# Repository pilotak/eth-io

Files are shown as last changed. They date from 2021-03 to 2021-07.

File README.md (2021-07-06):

<p align="center">
  
</p>
<p align="center">
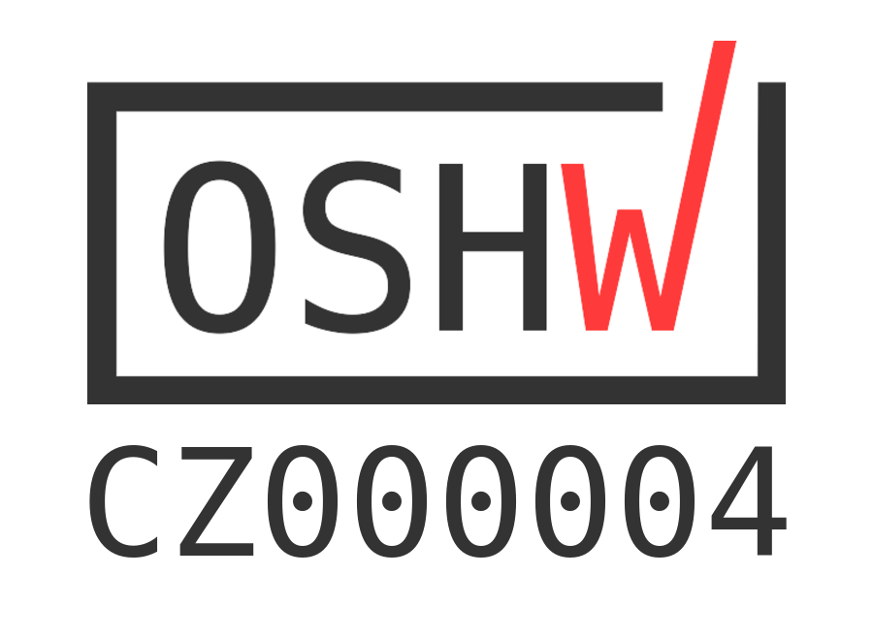
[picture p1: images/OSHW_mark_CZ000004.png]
  
</p>

# ETH IO
ESP32 based ethernet I/O board for home automation compatible with ESPHome, Tasmota, etc.

**Features**:
- wide range of input voltage 6-28V
- 4x opto-isolated "fast" operation inputs (connected to GPIO)
- 16x opto-isolated general inputs (connected to MCP23017 expander)
- 2x PWM capable low-side fully protected switches (connected to GPIO)
- 16x low-side fully protected switches for switching the non-latching relays or SSR relays (connected to MCP23017 expander)
- daisy chain design - see below

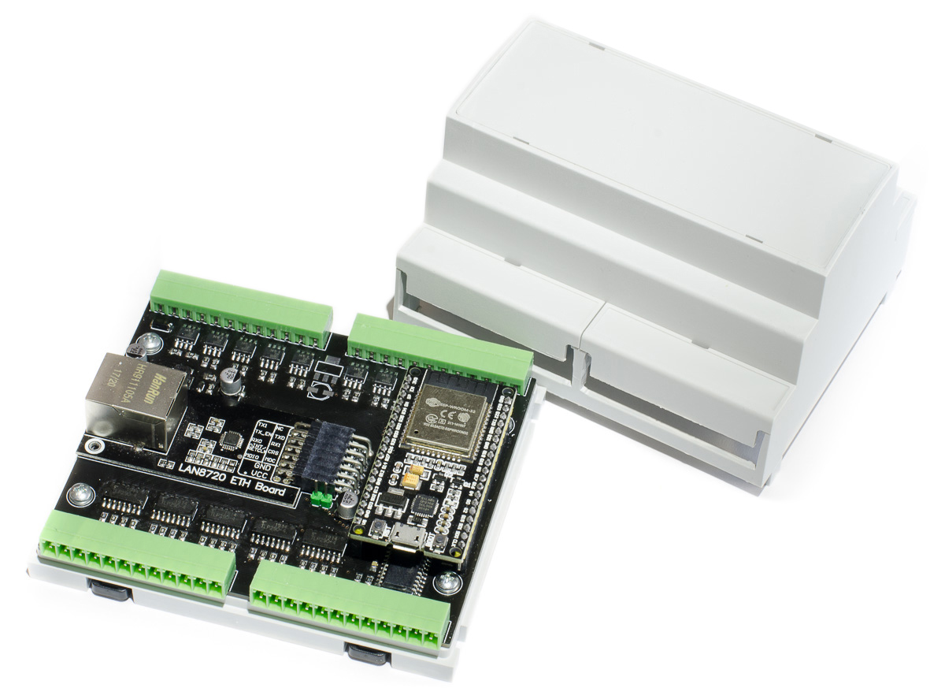
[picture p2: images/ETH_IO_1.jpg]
ETH_IO_1

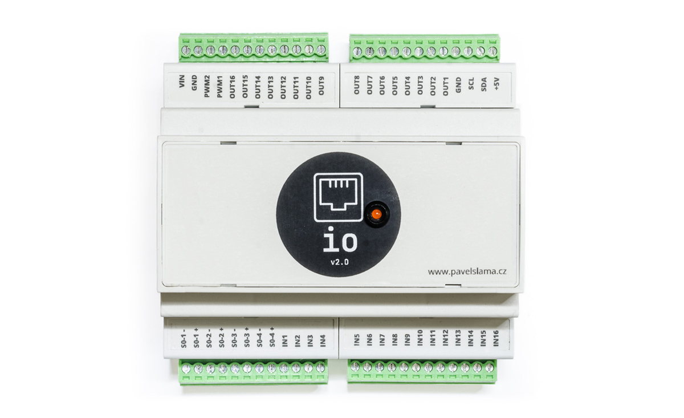
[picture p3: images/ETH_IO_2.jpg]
ETH_IO_2


## Basic wiring
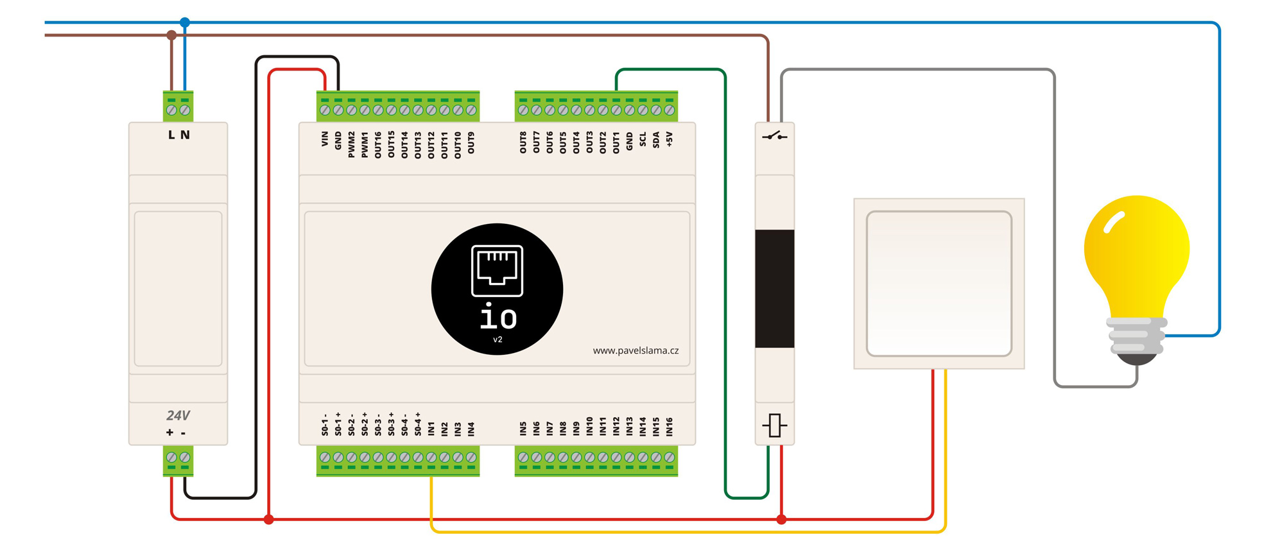
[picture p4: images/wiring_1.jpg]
Wiring 1


## "Fast" inputs
Are meant to be used for reading pulses from utility meter ie. power meter with S0 output
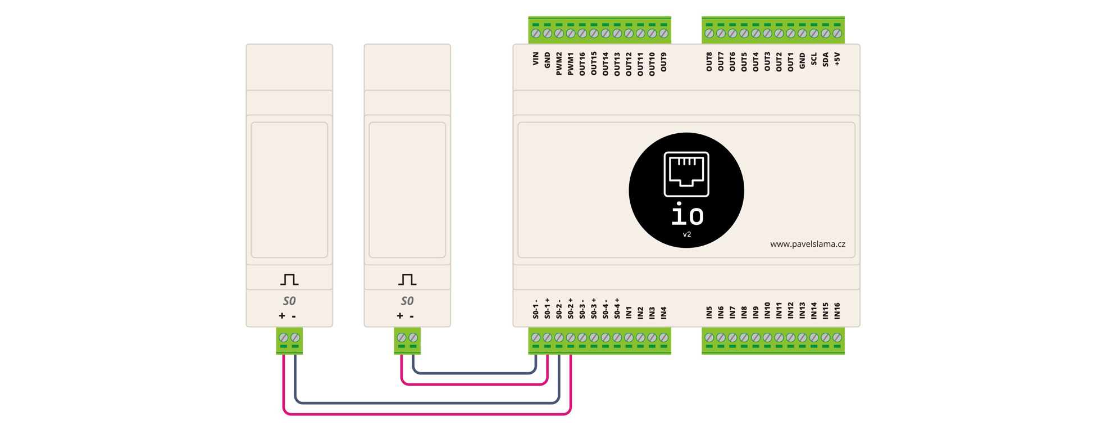
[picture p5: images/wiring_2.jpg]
Wiring 2


## Daisy chain design
Should you need more inputs/outputs (up to 96 more inputs/outputs or combination thanks to changing the address of MCP23017) you can use the same PCB. Just don't populate ETH breakout board and ESP32 and solder AMS1117-3.3 with its capacitor. The boards will be connected via SDA/SCL but thanks to a bus buffer (P82B96) communication can easilly be made up to 20 meters (possibly more by reducing speed of I2C bus)!
> In this mode the "slave" device can't make use of S0 inputs nor the PWM outputs

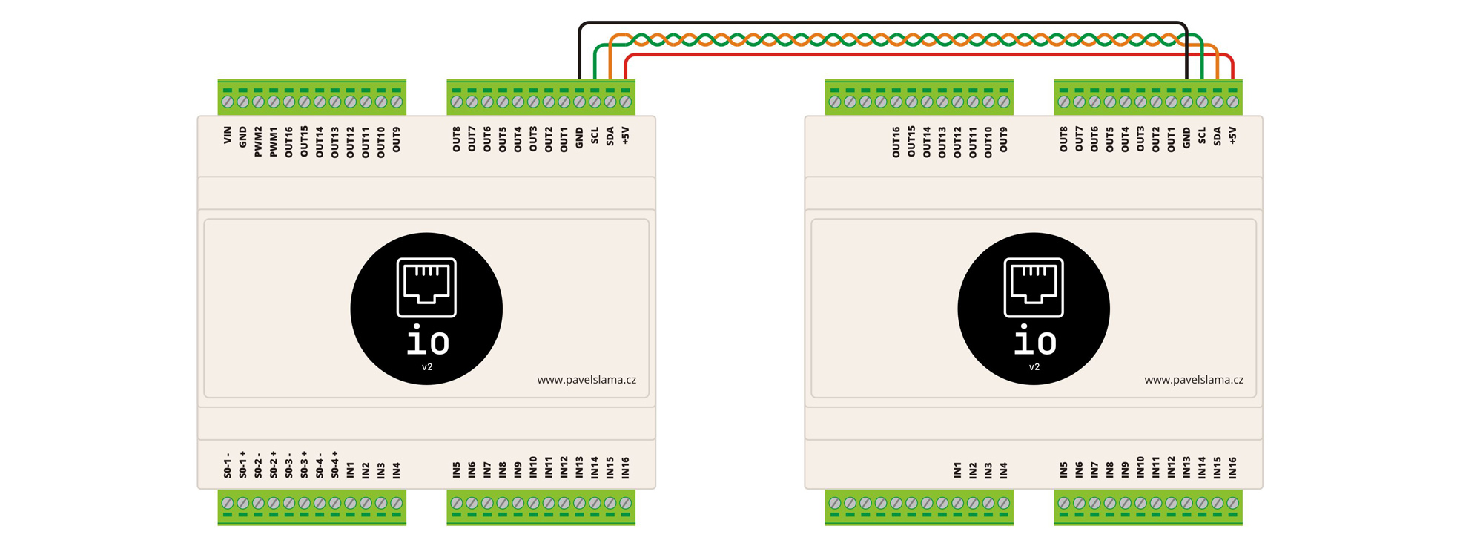
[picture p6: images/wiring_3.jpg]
Wiring 3


_For more information please visit [wiki](https://github.com/pilotak/eth-io/wiki)_

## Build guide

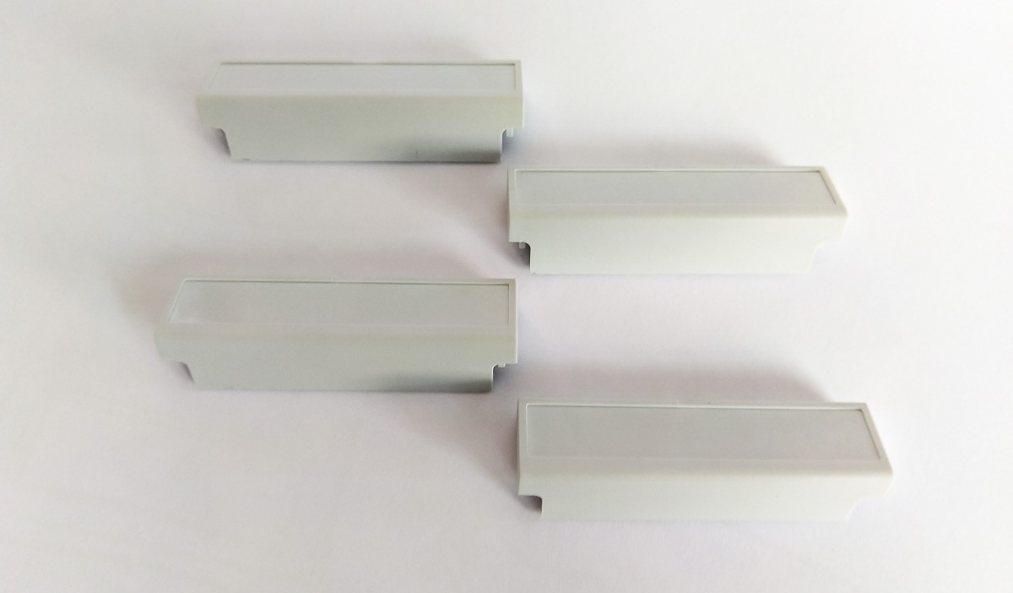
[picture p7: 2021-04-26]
images/assembly/7.jpg

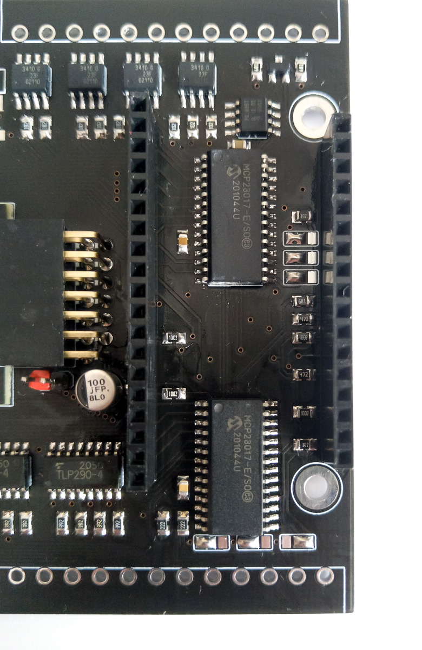
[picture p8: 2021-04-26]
images/assembly/3.jpg

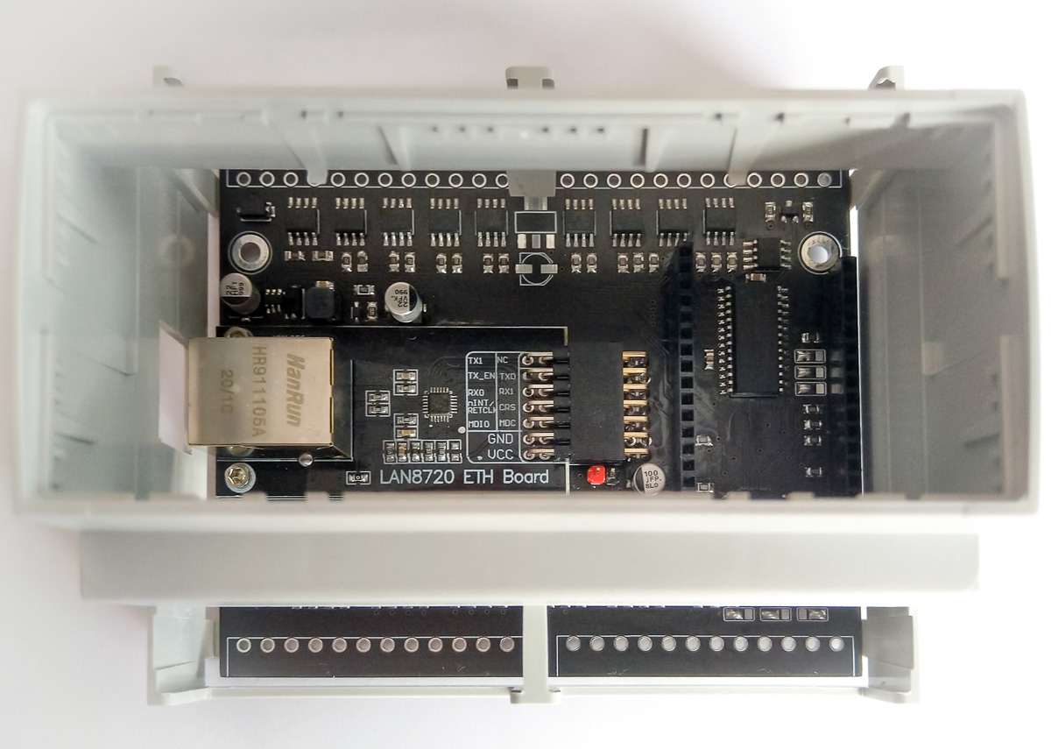
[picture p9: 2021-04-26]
images/assembly/2.jpg

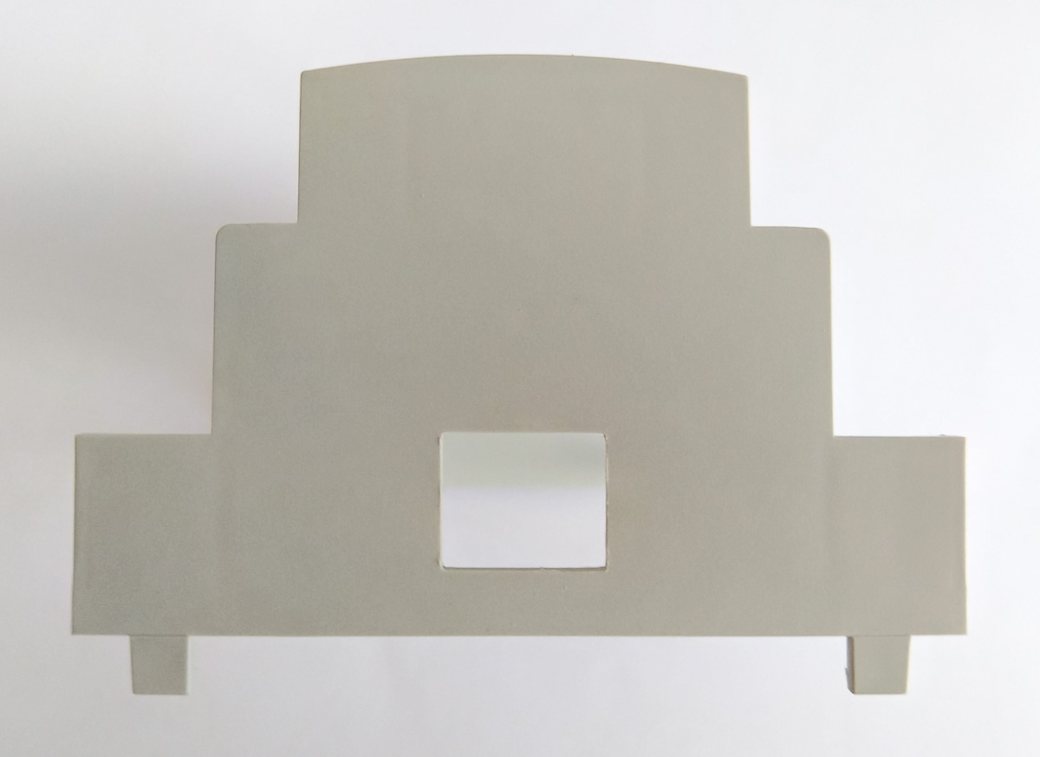
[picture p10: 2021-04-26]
images/assembly/5.jpg

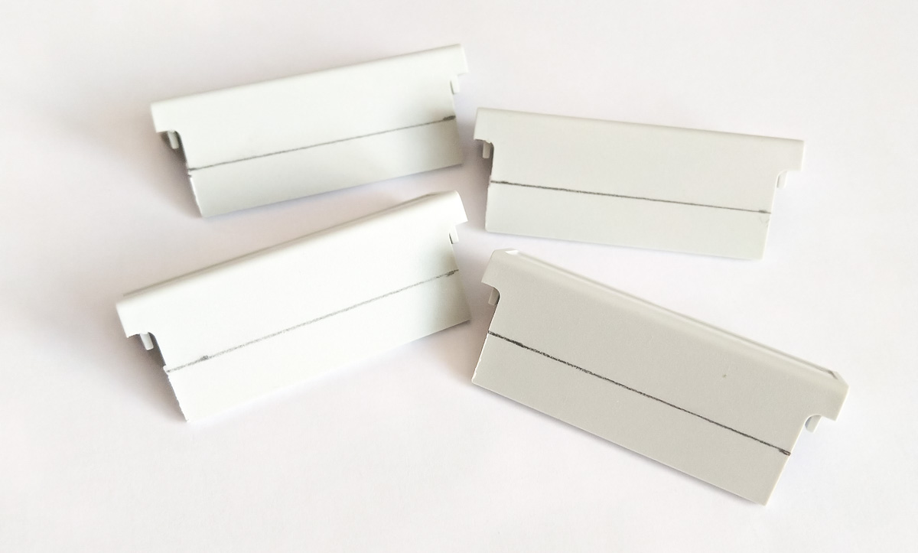
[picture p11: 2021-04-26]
images/assembly/6.jpg

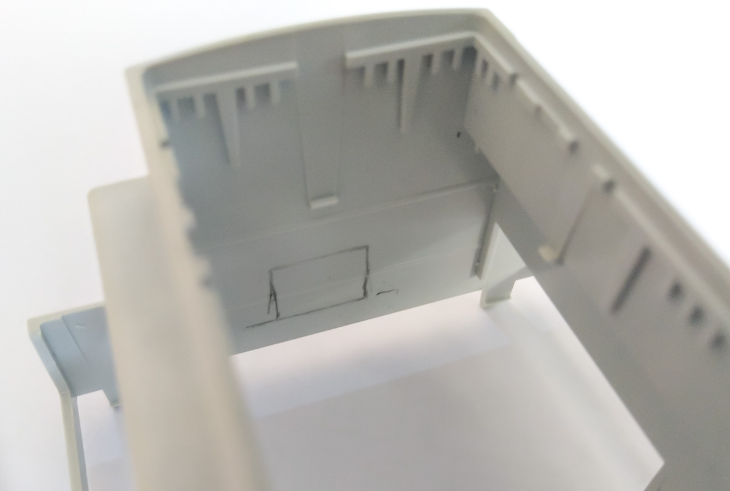
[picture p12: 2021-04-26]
images/assembly/4.jpg

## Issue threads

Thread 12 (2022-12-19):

Add topside eth jumper image

mDubovsky, 2022-12-19:
### Discussed in https://github.com/pilotak/eth-io/discussions/8

<div type='discussions-op-text'>

<sup>Originally posted by **mDubovsky** December 19, 2022</sup>
Some compatible ethernet modules have the oscillator on the top side of the PCB.
We should add photo of the jumper wire in this configuration...
</div>

We should add the image to the repository and change the wiki as well.
As mentioned in the discussion, we should also mention that a certain kind of the top-side oscillator variety of the ethernet breakout board is not compatible with the module because of wrong dimensions.

mDubovsky, 2022-12-21:
Image added to the repository and wiki assembly page has been modified.

Closed 2022-12-21.

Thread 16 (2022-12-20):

Add basic electrical parameters to the readme

mDubovsky, 2022-12-20:
### Discussed in https://github.com/pilotak/eth-io/discussions/7

<div type='discussions-op-text'>

<sup>Originally posted by **mDubovsky** December 19, 2022</sup>
While assembling the whole system you have to search for values in datasheets and calculate other values.
It would be helpful to have basic parameters in readme such as (but not limited to):

- Maximum current draw of the whole module during heavy network load
- Maximum switched voltage
- Maximum switched current
- Min/Max input signal voltage</div>

pilotak, 2022-12-26:
Average current consumption is 1W - (0.4A@24V, 0.8A@12V) when no input (outputs don't matter)
1 input consumes 6mA@24V

the highest current is during power-on when capacitors are also being charged peak 184mA@24V for 5ms
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

chrismazanec, 2024-02-14:
@pilotak you probably mean 0.04A@24V and 0.08A@12V? (~1W)

how is the max input current 0.6A calculated then? 14,4W seems too much, is that a mistake?
https://github.com/pilotak/eth-io/blob/v3/stickers/ETH-IO_v3_stickers.pdf

thank you

pilotak, 2024-02-14:
@chrismazanec yes 1W (0.04A@24V and 0.08A@12V) sorry

How i calculated it - 0.144W*20(inputs) + 4.416W(startup + ethernet stuff) = 7.3W continuous minimum. I tend to use double the amount i need, as when you reaching the top of current source from power supply, the current is limited, its heat is noticable and i don't like pushing it to the limits. But this is only my practice. You also have to take into account the measurement speed...

On your power supply - it depends. If most of the relays will be switched on and you turn on another, the current might be limited and might not turn on. This is because of the coil in the relay (induction load). But that is a theory only, i'm sure it will be fine in real life, even though i would choose 30W (next step in meanwell).

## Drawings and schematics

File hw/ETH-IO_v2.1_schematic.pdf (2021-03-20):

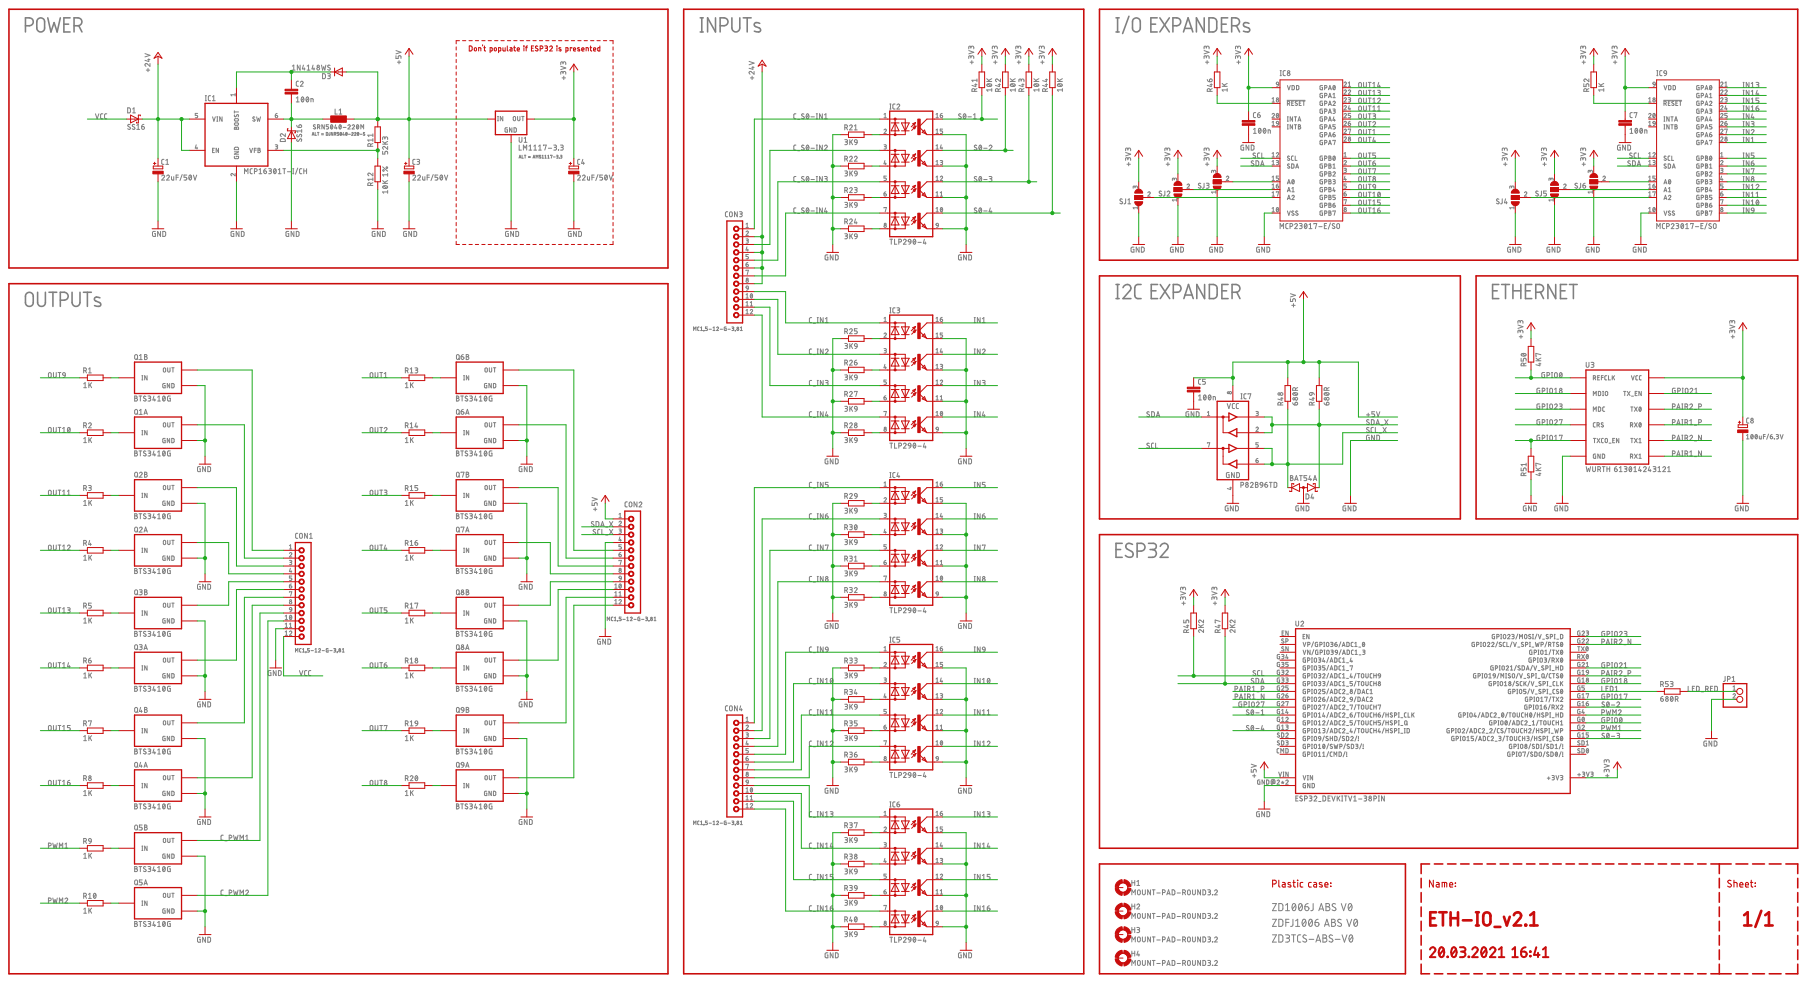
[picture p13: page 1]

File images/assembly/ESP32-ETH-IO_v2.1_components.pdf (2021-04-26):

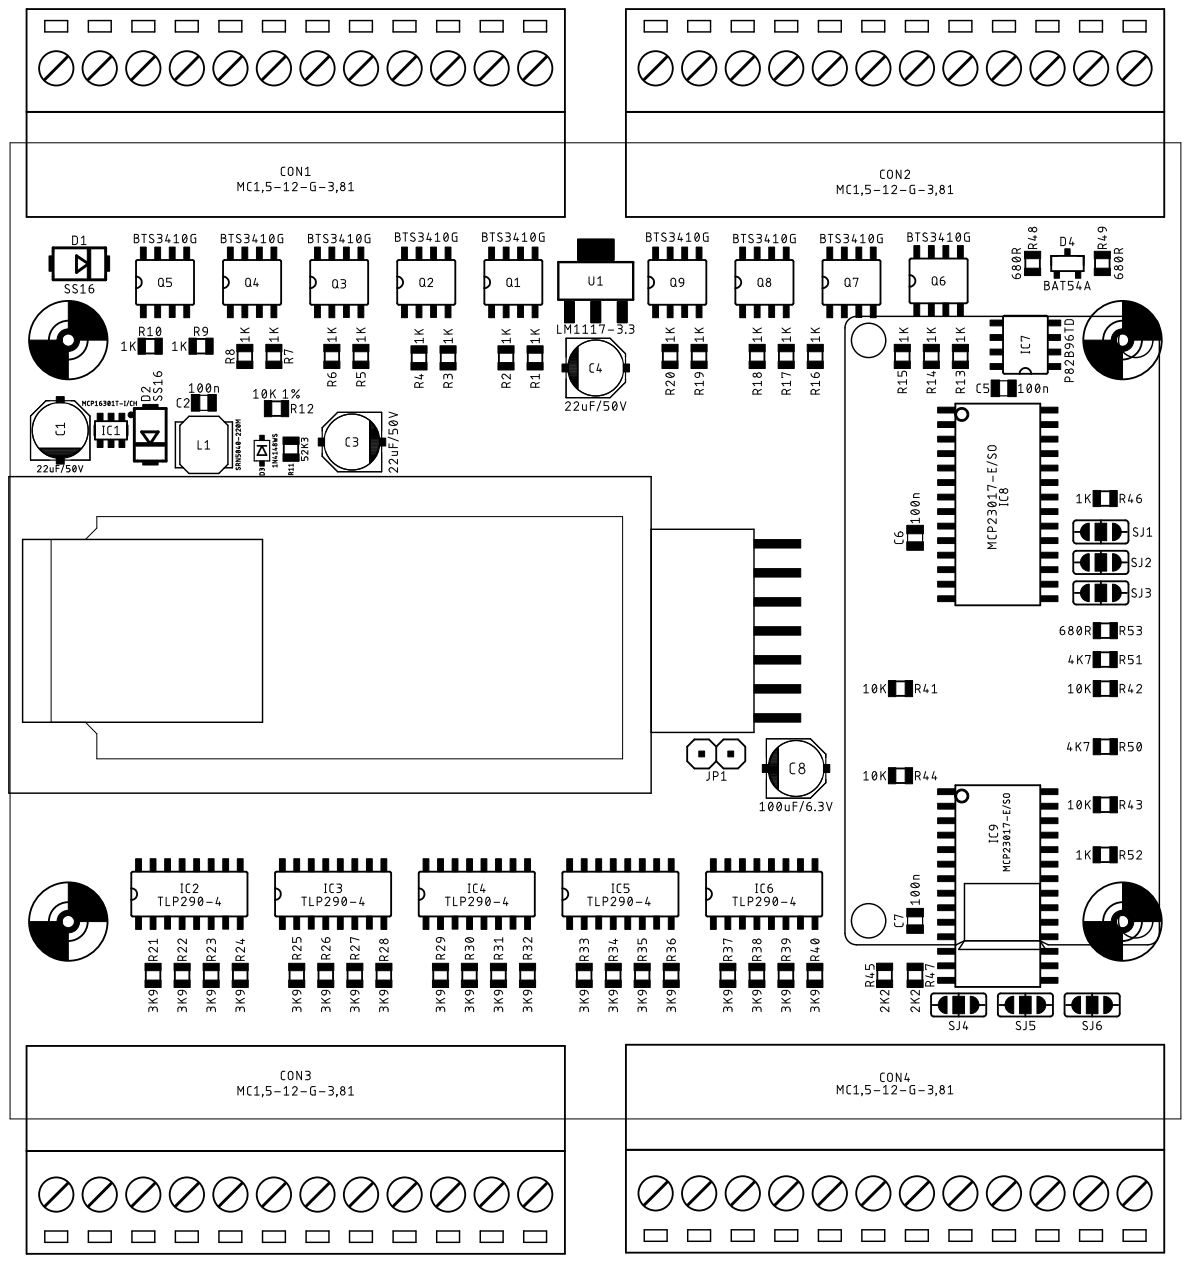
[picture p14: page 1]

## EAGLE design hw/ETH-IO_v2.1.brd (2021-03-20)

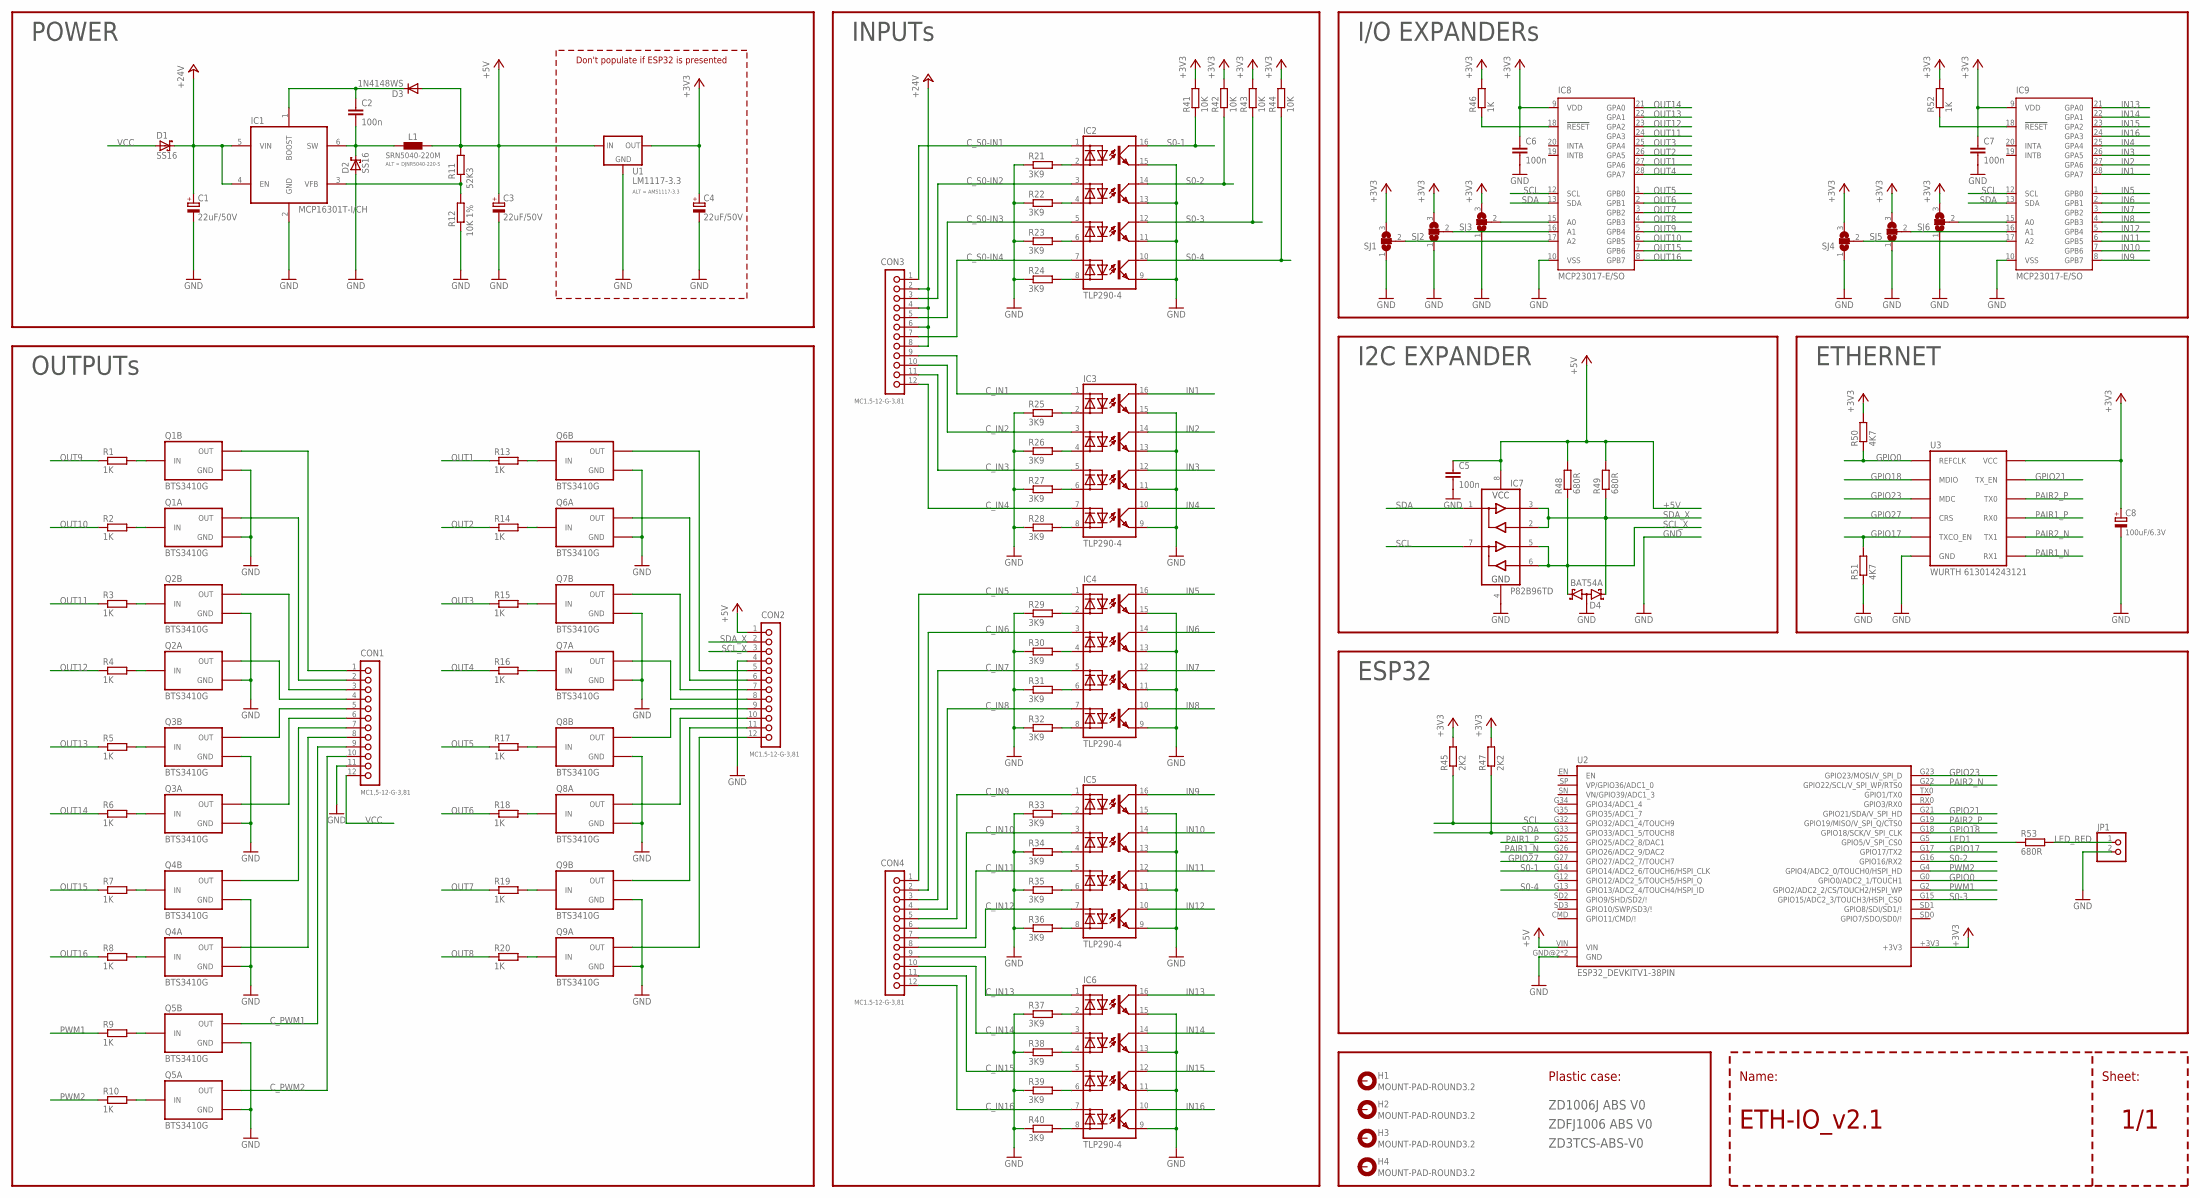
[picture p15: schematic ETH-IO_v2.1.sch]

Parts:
C1, C3, C4: 22uF/50V; PANASONIC_C
C2, C5, C6, C7: 100n; C0805
C8: 100uF/6.3V; PANASONIC_C
CON1, CON2, CON3, CON4: MC1,5-12-G-3,81; MC1,5/12-G-3,81
D1, D2: SS16; DO214AC
D3: 1N4148WS; SOD323
D4: BAT54A; SOT23
H1, H2, H3, H4: MOUNT-PAD-ROUND3.2; 3,2-PAD
IC1: MCP16301T-I/CH; SOT23-6
IC2, IC3, IC4, IC5, IC6: TLP290-4; SO16
IC7: P82B96TD; SO08
IC8, IC9: MCP23017-E/SO; SO28W
JP1: PINHD-1X02_2.54-S; 1X02-S
L1: SRN5040-220M; L5040
Q1, Q2, Q3, Q4, Q5, Q6, Q7, Q8, Q9: BTS3410G; SO8
R1, R2, R3, R4, R5, R6, R7, R8, R9, R10, R13, R14, R15, R16, R17, R18, R19, R20, R46, R52: 1K; R0805
R11: 52K3; R0805
R12: 10K 1%; R0805
R21, R22, R23, R24, R25, R26, R27, R28, R29, R30, R31, R32, R33, R34, R35, R36, R37, R38, R39, R40: 3K9; R0805
R41, R42, R43, R44: 10K; R0805
R45, R47: 2K2; R0805
R48, R49, R53: 680R; R0805
R50, R51: 4K7; R0805
SJ1, SJ2, SJ3, SJ4, SJ5, SJ6: SJ2W; SJ_2
U1: LM1117-3.3; SOT223
U2: ESP32_DEVKITV1-38PIN; ESP32_DEVKITV1_38PIN
U3: WURTH 613014243121; LAN8720_ETH_BOARD

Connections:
+3V3: C4.+, C6.1, C7.1, C8.+, IC8.9 (VDD), IC9.9 (VDD), R41.2, R42.2, R43.2, R44.2, R45.2, R46.2, R47.2, R50.2, R52.2, SJ1.3, SJ2.3, SJ3.3, SJ4.3, SJ5.3, SJ6.3, U1.2 (OUT), U1.4 (OUT), U2.+3V3, U3.VCC, U3.VCC@1 (VCC)
+5V: C3.+, C5.1, CON2.1, D3.A, IC7.8 (VCC), L1.1, R11.2, R48.2, R49.2, U1.3 (IN), U2.VIN
+24V: C1.+, CON3.2, CON3.4, CON3.6, CON3.8, D1.C, IC1.4 (EN), IC1.5 (VIN)
C_IN1: CON3.9, IC3.1 (A1)
C_IN2: CON3.10, IC3.3 (A2)
C_IN3: CON3.11, IC3.5 (A3)
C_IN4: CON3.12, IC3.7 (A4)
C_IN5: CON4.1, IC4.1 (A1)
C_IN6: CON4.2, IC4.3 (A2)
C_IN7: CON4.3, IC4.5 (A3)
C_IN8: CON4.4, IC4.7 (A4)
C_IN9: CON4.5, IC5.1 (A1)
C_IN10: CON4.6, IC5.3 (A2)
C_IN11: CON4.7, IC5.5 (A3)
C_IN12: CON4.8, IC5.7 (A4)
C_IN13: CON4.9, IC6.1 (A1)
C_IN14: CON4.10, IC6.3 (A2)
C_IN15: CON4.11, IC6.5 (A3)
C_IN16: CON4.12, IC6.7 (A4)
C_OUT1: CON2.5, Q6.5 (OUT), Q6.6 (OUT)
C_OUT2: CON2.6, Q6.7 (OUT), Q6.8 (OUT)
C_OUT3: CON2.7, Q7.5 (OUT), Q7.6 (OUT)
C_OUT4: CON2.8, Q7.7 (OUT), Q7.8 (OUT)
C_OUT5: CON2.9, Q8.5 (OUT), Q8.6 (OUT)
C_OUT6: CON2.10, Q8.7 (OUT), Q8.8 (OUT)
C_OUT7: CON2.11, Q9.5 (OUT), Q9.6 (OUT)
C_OUT8: CON2.12, Q9.7 (OUT), Q9.8 (OUT)
C_OUT9: CON1.1, Q1.5 (OUT), Q1.6 (OUT)
C_OUT10: CON1.2, Q1.7 (OUT), Q1.8 (OUT)
C_OUT11: CON1.3, Q2.5 (OUT), Q2.6 (OUT)
C_OUT12: CON1.4, Q2.7 (OUT), Q2.8 (OUT)
C_OUT13: CON1.5, Q3.5 (OUT), Q3.6 (OUT)
C_OUT14: CON1.6, Q3.7 (OUT), Q3.8 (OUT)
C_OUT15: CON1.7, Q4.5 (OUT), Q4.6 (OUT)
C_OUT16: CON1.8, Q4.7 (OUT), Q4.8 (OUT)
C_PWM1: CON1.9, Q5.5 (OUT), Q5.6 (OUT)
C_PWM2: CON1.10, Q5.7 (OUT), Q5.8 (OUT)
C_S0-IN1: CON3.1, IC2.1 (A1)
C_S0-IN2: CON3.3, IC2.3 (A2)
C_S0-IN3: CON3.5, IC2.5 (A3)
C_S0-IN4: CON3.7, IC2.7 (A4)
GND: C1.-, C3.-, C4.-, C5.2, C6.2, C7.2, C8.-, CON1.11, CON2.4, D2.A, D4.3 (AA), IC1.2 (GND), IC2.9 (EMIT4), IC2.11 (EMIT3), IC2.13 (EMIT2), IC2.15 (EMIT1), IC3.9 (EMIT4), IC3.11 (EMIT3), IC3.13 (EMIT2), IC3.15 (EMIT1), IC4.9 (EMIT4), IC4.11 (EMIT3), IC4.13 (EMIT2), IC4.15 (EMIT1), IC5.9 (EMIT4), IC5.11 (EMIT3), IC5.13 (EMIT2), IC5.15 (EMIT1), IC6.9 (EMIT4), IC6.11 (EMIT3), IC6.13 (EMIT2), IC6.15 (EMIT1), IC7.4 (GND), IC8.10 (VSS), IC9.10 (VSS), JP1.2, Q1.1 (GND), Q1.3 (GND), Q2.1 (GND), Q2.3 (GND), Q3.1 (GND), Q3.3 (GND), Q4.1 (GND), Q4.3 (GND), Q5.1 (GND), Q5.3 (GND), Q6.1 (GND), Q6.3 (GND), Q7.1 (GND), Q7.3 (GND), Q8.1 (GND), Q8.3 (GND), Q9.1 (GND), Q9.3 (GND), R12.1, R21.1, R22.1, R23.1, R24.1, R25.1, R26.1, R27.1, R28.1, R29.1, R30.1, R31.1, R32.1, R33.1, R34.1, R35.1, R36.1, R37.1, R38.1, R39.1, R40.1, R51.1, SJ1.1, SJ2.1, SJ3.1, SJ4.1, SJ5.1, SJ6.1, U1.1 (GND), U2.GND@2 (GND), U2.GND@3 (GND), U3.GND, U3.GND@1 (GND)
GPIO0: R50.1, U2.G0 (GPIO0/ADC2_1/TOUCH1), U3.INT (REFCLK)
GPIO17: R51.2, U2.G17 (GPIO17/TX2), U3.TXCO_EN
GPIO18: U2.G18 (GPIO18/SCK/V_SPI_CLK), U3.MDIO
GPIO21: U2.G21 (GPIO21/SDA/V_SPI_HD), U3.TX_EN
GPIO23: U2.G23 (GPIO23/MOSI/V_SPI_D), U3.MDC
GPIO27: U2.G27 (GPIO27/ADC2_7/TOUCH7), U3.CRS
IN1: IC3.16 (COL1), IC9.28 (GPA7)
IN2: IC3.14 (COL2), IC9.27 (GPA6)
IN3: IC3.12 (COL3), IC9.26 (GPA5)
IN4: IC3.10 (COL4), IC9.25 (GPA4)
IN5: IC4.16 (COL1), IC9.1 (GPB0)
IN6: IC4.14 (COL2), IC9.2 (GPB1)
IN7: IC4.12 (COL3), IC9.3 (GPB2)
IN8: IC4.10 (COL4), IC9.4 (GPB3)
IN9: IC5.16 (COL1), IC9.8 (GPB7)
IN10: IC5.14 (COL2), IC9.7 (GPB6)
IN11: IC5.12 (COL3), IC9.6 (GPB5)
IN12: IC5.10 (COL4), IC9.5 (GPB4)
IN13: IC6.16 (COL1), IC9.21 (GPA0)
IN14: IC6.14 (COL2), IC9.22 (GPA1)
IN15: IC6.12 (COL3), IC9.23 (GPA2)
IN16: IC6.10 (COL4), IC9.24 (GPA3)
LED1: R53.1, U2.G5 (GPIO5/V_SPI_CS0)
LED_RED: JP1.1, R53.2
unnamed: IC9.15 (A0), SJ6.2
unnamed: IC8.16 (A1), SJ2.2
unnamed: Q1.2 (IN), R2.2
unnamed: Q1.4 (IN), R1.2
unnamed: IC8.18 (!RESET), R46.1
unnamed: IC9.18 (!RESET), R52.1
unnamed: IC8.15 (A0), SJ3.2
unnamed: Q5.4 (IN), R9.2
unnamed: Q5.2 (IN), R10.2
unnamed: IC9.16 (A1), SJ5.2
unnamed: IC3.2 (C1), R25.2
unnamed: IC3.4 (C2), R26.2
unnamed: IC3.6 (C3), R27.2
unnamed: IC3.8 (C4), R28.2
unnamed: IC4.2 (C1), R29.2
unnamed: IC4.4 (C2), R30.2
unnamed: IC4.6 (C3), R31.2
unnamed: IC4.8 (C4), R32.2
unnamed: IC5.2 (C1), R33.2
unnamed: IC5.4 (C2), R34.2
unnamed: IC5.6 (C3), R35.2
unnamed: IC5.8 (C4), R36.2
unnamed: IC6.2 (C1), R37.2
unnamed: IC6.4 (C2), R38.2
unnamed: IC6.6 (C3), R39.2
unnamed: IC6.8 (C4), R40.2
unnamed: IC9.17 (A2), SJ4.2
unnamed: Q2.4 (IN), R3.2
unnamed: Q2.2 (IN), R4.2
unnamed: IC8.17 (A2), SJ1.2
unnamed: Q3.4 (IN), R5.2
unnamed: Q3.2 (IN), R6.2
unnamed: Q4.4 (IN), R7.2
unnamed: Q4.2 (IN), R8.2
unnamed: IC2.2 (C1), R21.2
unnamed: Q6.4 (IN), R13.2
unnamed: Q6.2 (IN), R14.2
unnamed: Q7.4 (IN), R15.2
unnamed: Q7.2 (IN), R16.2
unnamed: Q8.4 (IN), R17.2
unnamed: Q8.2 (IN), R18.2
unnamed: Q9.4 (IN), R19.2
unnamed: Q9.2 (IN), R20.2
unnamed: IC2.4 (C2), R22.2
unnamed: IC2.6 (C3), R23.2
unnamed: IC2.8 (C4), R24.2
unnamed: C2.2, D2.C, IC1.6 (SW), L1.2
unnamed: C2.1, D3.C, IC1.1 (BOOST)
unnamed: IC1.3 (VFB), R11.1, R12.2
OUT1: IC8.27 (GPA6), R13.1
OUT2: IC8.26 (GPA5), R14.1
OUT3: IC8.25 (GPA4), R15.1
OUT4: IC8.28 (GPA7), R16.1
OUT5: IC8.1 (GPB0), R17.1
OUT6: IC8.2 (GPB1), R18.1
OUT7: IC8.3 (GPB2), R19.1
OUT8: IC8.4 (GPB3), R20.1
OUT9: IC8.5 (GPB4), R1.1
OUT10: IC8.6 (GPB5), R2.1
OUT11: IC8.24 (GPA3), R3.1
OUT12: IC8.23 (GPA2), R4.1
OUT13: IC8.22 (GPA1), R5.1
OUT14: IC8.21 (GPA0), R6.1
OUT15: IC8.7 (GPB6), R7.1
OUT16: IC8.8 (GPB7), R8.1
PAIR1_N: U2.G26 (GPIO26/ADC2_9/DAC2), U3.RX1
PAIR1_P: U2.G25 (GPIO25/ADC2_8/DAC1), U3.RX0
PAIR2_N: U2.G22 (GPIO22/SCL/V_SPI_WP/RTS0), U3.TX1
PAIR2_P: U2.G19 (GPIO19/MISO/V_SPI_Q/CTS0), U3.TX0
PWM1: R9.1, U2.G2 (GPIO2/ADC2_2/CS/TOUCH2/HSPI_WP)
PWM2: R10.1, U2.G4 (GPIO4/ADC2_0/TOUCH0/HSPI_HD)
S0-1: IC2.16 (COL1), R41.1, U2.G14 (GPIO14/ADC2_6/TOUCH6/HSPI_CLK)
S0-2: IC2.14 (COL2), R42.1, U2.G16 (GPIO16/RX2)
S0-3: IC2.12 (COL3), R43.1, U2.G15 (GPIO15/ADC2_3/TOUCH3/HSPI_CS0)
S0-4: IC2.10 (COL4), R44.1, U2.G13 (GPIO13/ADC2_4/TOUCH4/HSPI_ID)
SCL: IC7.7 (SY), IC8.12 (SCL), IC9.12 (SCL), R45.1, U2.G32 (GPIO32/ADC1_4/TOUCH9)
SCL_X: CON2.3, D4.1 (K1), IC7.5 (TY), IC7.6 (RY), R48.1
SDA: IC7.1 (SX), IC8.13 (SDA), IC9.13 (SDA), R47.1, U2.G33 (GPIO33/ADC1_5/TOUCH8)
SDA_X: CON2.2, D4.2 (K2), IC7.2 (RX), IC7.3 (TX), R49.1
VCC: CON1.12, D1.A

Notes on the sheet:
INPUTs
I/O EXPANDERs
OUTPUTs
POWER
I2C EXPANDER
ETHERNET
ZDFJ1006 ABS V0
ZD3TCS-ABS-V0
ZD1006J ABS V0
Don't populate if ESP32 is presented
ESP32
ETH-IO_v2.1
Sheet:
Name:
Plastic case:

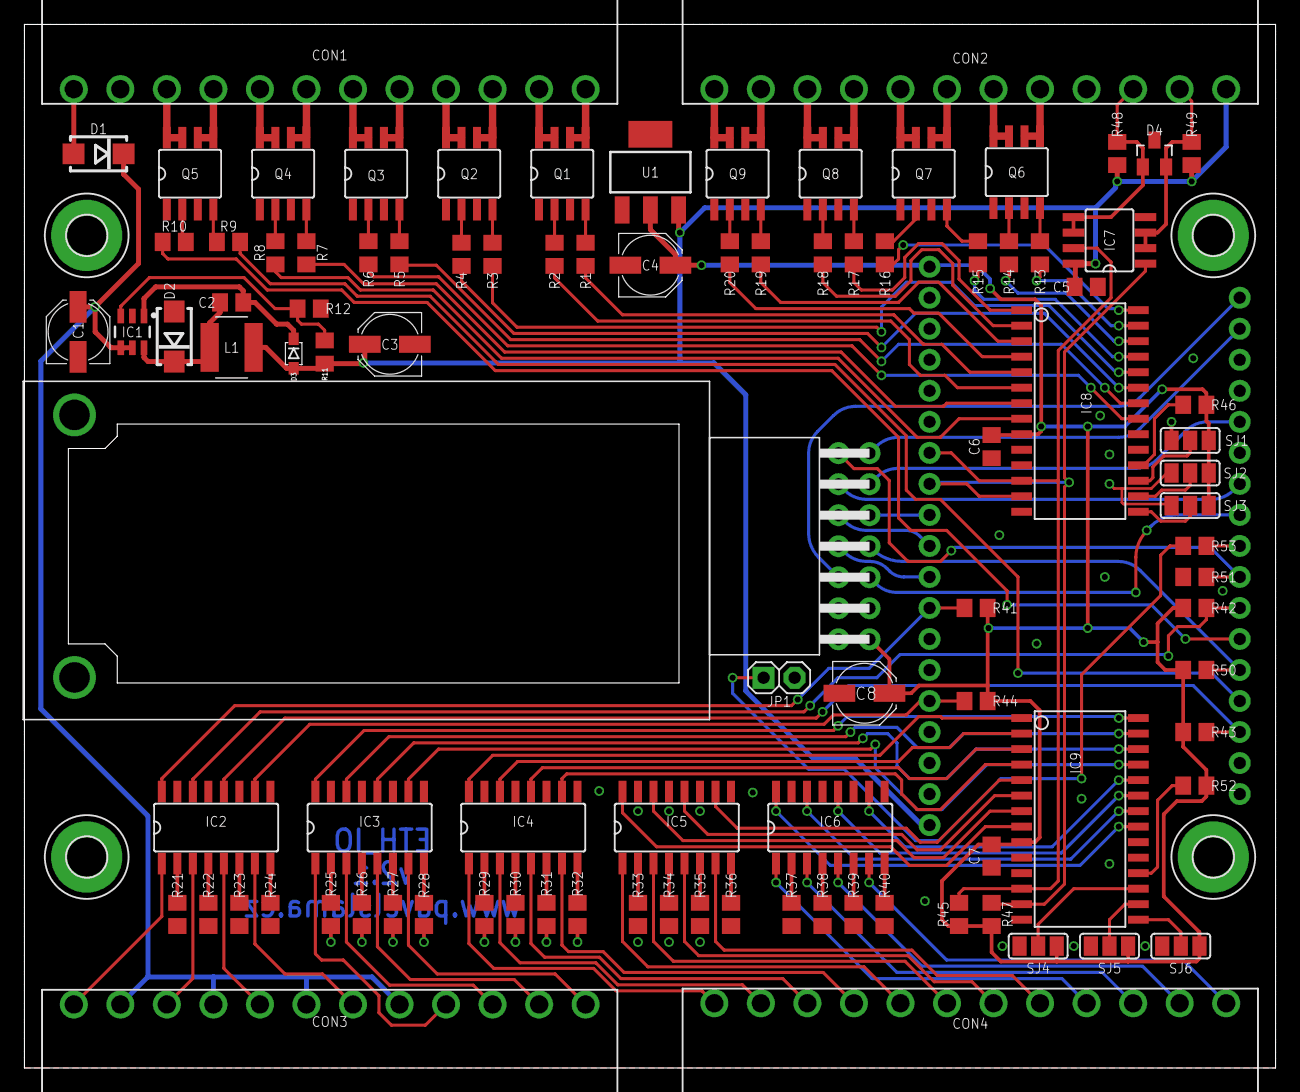
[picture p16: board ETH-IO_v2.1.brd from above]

Board: 2 copper layers, 102.4 x 85.4 mm, 102 parts (0 on the bottom side), 146 nets.

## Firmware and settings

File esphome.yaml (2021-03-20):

esphome:
  name: eth_io
  platform: ESP32
  board: nodemcu-32s

ethernet:
  type: LAN8720
  mdc_pin: GPIO23
  mdio_pin: GPIO18
  phy_addr: 1
  clk_mode: GPIO0_IN
  power_pin: GPIO17

logger:

ota:

api:

i2c:
  sda: GPIO33
  scl: GPIO32
  frequency: 100kHz

mcp23017:
  - id: out_hub1
    address: 0x20

  - id: in_hub1
    address: 0x21

time:
  - platform: homeassistant
    id: homeassistant_time
    timezone: "Europe/Prague"

status_led:
  pin:
    number: GPIO5

sensor:
  - platform: pulse_counter
    pin: GPIO14
    name: "Power consumption 1"
    id: power1
    unit_of_measurement: 'Wh'
    internal_filter: 13us
    filters:
      - multiply: 16.66666666666
    count_mode:
      rising_edge: DISABLE
      falling_edge: INCREMENT

  - platform: pulse_counter
    pin: GPIO16
    name: "Power consumption 2"
    id: power2
    unit_of_measurement: 'Wh'
    internal_filter: 13us
    filters:
      - multiply: 16.66666666666
    count_mode:
      rising_edge: DISABLE
      falling_edge: INCREMENT

  - platform: pulse_counter
    pin: GPIO15
    name: "Power consumption 3"
    id: power3
    unit_of_measurement: 'Wh'
    internal_filter: 13us
    filters:
      - multiply: 16.66666666666
    count_mode:
      rising_edge: DISABLE
      falling_edge: INCREMENT

  - platform: pulse_counter
    pin: GPIO13
    name: "Power consumption 4"
    id: power4
    unit_of_measurement: 'Wh'
    internal_filter: 13us
    filters:
      - multiply: 16.66666666666
    count_mode:
      rising_edge: DISABLE
      falling_edge: INCREMENT

  - platform: total_daily_energy
    name: "Daily power consumption 1"
    icon: "mdi:current-ac"
    power_id: power1
    unit_of_measurement: 'kWh'
    filters:
      - multiply: 0.001

  - platform: total_daily_energy
    name: "Daily power consumption 2"
    icon: "mdi:current-ac"
    power_id: power2
    unit_of_measurement: 'kWh'
    filters:
      - multiply: 0.001

  - platform: total_daily_energy
    name: "Daily power consumption 3"
    icon: "mdi:current-ac"
    power_id: power3
    unit_of_measurement: 'kWh'
    filters:
      - multiply: 0.001

  - platform: total_daily_energy
    name: "Daily power consumption 4"
    icon: "mdi:current-ac"
    power_id: power4
    unit_of_measurement: 'kWh'
    filters:
      - multiply: 0.001

binary_sensor:
  - platform: gpio
    id: in1
    pin:
      mcp23017: in_hub1
      number: 7
      mode: INPUT_PULLUP
      inverted: True
    filters:
      - delayed_on: 3ms
      - delayed_off: 3ms
    on_click:
      then:
        - switch.toggle: output1

  - platform: gpio
    id: in2
    pin:
      mcp23017: in_hub1
      number: 6
      mode: INPUT_PULLUP
      inverted: True
    filters:
      - delayed_on: 3ms
      - delayed_off: 3ms
    on_click:
      then:
        - switch.toggle: output2

  - platform: gpio
    id: in3
    pin:
      mcp23017: in_hub1
      number: 5
      mode: INPUT_PULLUP
      inverted: True
    filters:
      - delayed_on: 3ms
      - delayed_off: 3ms
    on_click:
      then:
        - switch.toggle: output3

  - platform: gpio
    id: in4
    pin:
      mcp23017: in_hub1
      number: 4
      mode: INPUT_PULLUP
      inverted: True
    filters:
      - delayed_on: 3ms
      - delayed_off: 3ms
    on_click:
      then:
        - switch.toggle: output4

  - platform: gpio
    id: in5
    pin:
      mcp23017: in_hub1
      number: 8
      mode: INPUT_PULLUP
      inverted: True
    filters:
      - delayed_on: 3ms
      - delayed_off: 3ms
    on_click:
      then:
        - switch.toggle: output5

  - platform: gpio
    id: in6
    pin:
      mcp23017: in_hub1
      number: 9
      mode: INPUT_PULLUP
      inverted: True
    filters:
      - delayed_on: 3ms
      - delayed_off: 3ms
    on_click:
      then:
        - switch.toggle: output6

  - platform: gpio
    id: in7
    pin:
      mcp23017: in_hub1
      number: 10
      mode: INPUT_PULLUP
      inverted: True
    filters:
      - delayed_on: 3ms
      - delayed_off: 3ms
    on_click:
      then:
        - switch.toggle: output7

  - platform: gpio
    id: in8
    pin:
      mcp23017: in_hub1
      number: 11
      mode: INPUT_PULLUP
      inverted: True
    filters:
      - delayed_on: 3ms
      - delayed_off: 3ms
    on_click:
      then:
        - switch.toggle: output8

  - platform: gpio
    id: in9
    pin:
      mcp23017: in_hub1
      number: 15
      mode: INPUT_PULLUP
      inverted: True
    filters:
      - delayed_on: 3ms
      - delayed_off: 3ms
    on_click:
      then:
        - switch.toggle: output9

  - platform: gpio
    id: in10
    pin:
      mcp23017: in_hub1
      number: 14
      mode: INPUT_PULLUP
      inverted: True
    filters:
      - delayed_on: 3ms
      - delayed_off: 3ms
    on_click:
      then:
        - switch.toggle: output10

  - platform: gpio
    id: in11
    pin:
      mcp23017: in_hub1
      number: 13
      mode: INPUT_PULLUP
      inverted: True
    filters:
      - delayed_on: 3ms
      - delayed_off: 3ms
    on_click:
      then:
        - switch.toggle: output11

  - platform: gpio
    id: in12
    pin:
      mcp23017: in_hub1
      number: 12
      mode: INPUT_PULLUP
      inverted: True
    filters:
      - delayed_on: 3ms
      - delayed_off: 3ms
    on_click:
      then:
        - switch.toggle: output12

  - platform: gpio
    id: in13
    pin:
      mcp23017: in_hub1
      number: 0
      mode: INPUT_PULLUP
      inverted: True
    filters:
      - delayed_on: 3ms
      - delayed_off: 3ms
    on_click:
      then:
        - switch.toggle: output13

  - platform: gpio
    id: in14
    pin:
      mcp23017: in_hub1
      number: 1
      mode: INPUT_PULLUP
      inverted: True
    filters:
      - delayed_on: 3ms
      - delayed_off: 3ms
    on_click:
      then:
        - switch.toggle: output14

  - platform: gpio
    id: in15
    pin:
      mcp23017: in_hub1
      number: 2
      mode: INPUT_PULLUP
      inverted: True
    filters:
      - delayed_on: 3ms
      - delayed_off: 3ms
    on_click:
      then:
        - switch.toggle: output15

  - platform: gpio
    id: in16
    pin:
      mcp23017: in_hub1
      number: 3
      mode: INPUT_PULLUP
      inverted: True
    filters:
      - delayed_on: 3ms
      - delayed_off: 3ms
    on_click:
      then:
        - switch.toggle: output16
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

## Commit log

2021-03-21 wiring diagrams
2021-03-21 daisy chain update
